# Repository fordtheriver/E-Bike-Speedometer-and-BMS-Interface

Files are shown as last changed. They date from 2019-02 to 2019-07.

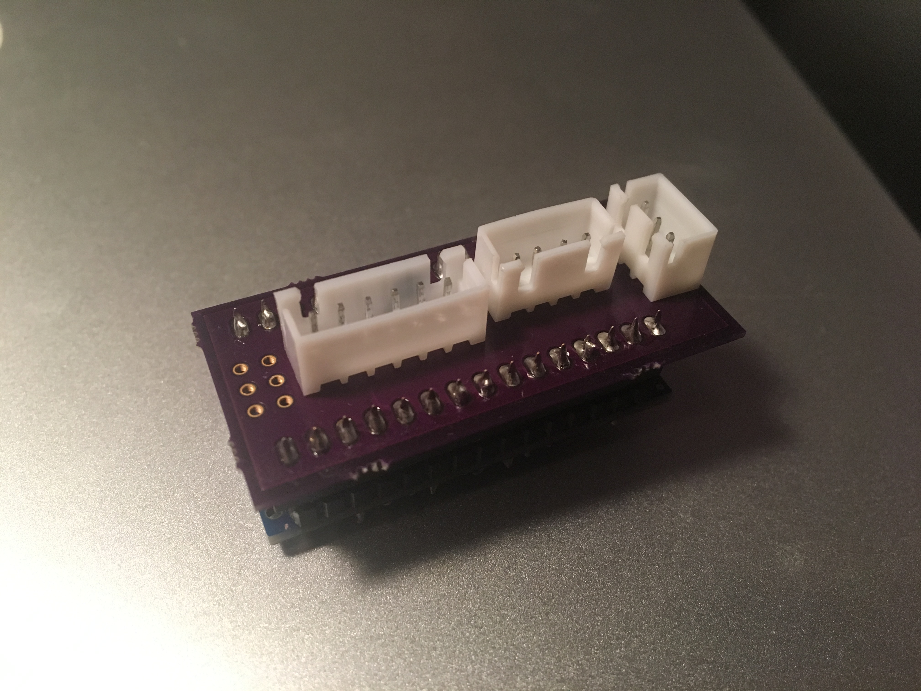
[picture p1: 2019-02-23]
Pictures/JST_Connectors.JPG

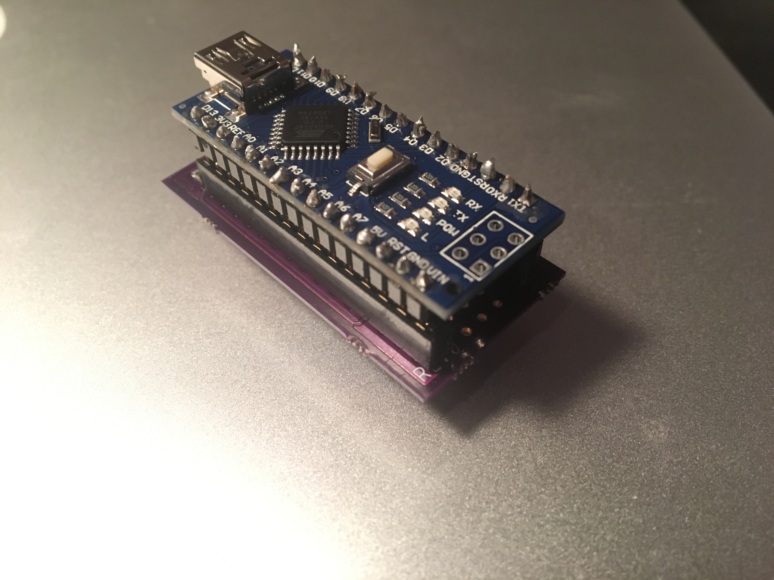
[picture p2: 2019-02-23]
Pictures/Arduino_Shield.JPG

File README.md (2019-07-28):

# E-Bike-Speedometer-and-BMS-Interface

**Updated 7/25/19** Completed, manufactured, and test REV4 of board. It works! REV3 is also complete.

This repository includes information needed to built a display to output the speed, mileage, power, current, pack voltage, individual cell voltage abd State of Charge of an electric bicycle/powerwall using an Arduino Nano! This repository includes the necessary Arduino files, a custom Arduino shield PCB designed in EAGLE and various information about the components required to build this system.

There are two versions of this system which you can build: <br /> 
**REV3:** This is a simple board that requires little soldering or PCB design experience. Beginners start here! <br /> 
**REV4:** This board is identical to REV3 but it embedds the arduino nano onto the board, instead of through-hole mounting a off-the-shelf arduino nano. <br /> 
Both REV's function identically. Think of REV3 as a demo board where you can develop firmware and prototype the system. REV4 gets into the low level side and allows for greater custimizations and smaller size.

Here is a brief list describing the necessary high level components for this system.

1. Arduino Nano. REV4 embeds the ATmega328P micrcoprocessor on the board to significantly reduce system size and weight. 

2. [20x4 LCD Display with I2C.](https://www.ebay.com/sch/i.html?_from=R40&_trksid=m570.l1313&_nkw=20x4+i2c+lcd+&_sacat=0). The I2C communication bus drastically reduces the number of wires going to the LCD and the \#include <LiquidCrystal_I2C.h> library seamlessly integrates the I2C protocol into your arduino. 

3. JBDTools Compatible BMS: Here is a [link](https://www.aliexpress.com/item/15S-Li-ion-Battery-Intelligent-Smart-BMS-with-Bluetooth-function-and-PC-software-UART-communication-PCB/32876909159.html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) to the one I purchased.  . Make sure the BMS you buy is compatible with JBDTools software. My arduino script uses the communication protocol used by the JBDTools software. This protocol can be found in an excel file call JBDTools Communication Protol at the homepage of this repository. [Simat](https://github.com/simat/BatteryMonitor/wiki/Generic-Chinese-Bluetooth-BMS-communication-protocol) also has a great description of it as well. 

4. DC/DC Converter. The linear voltage regulator on [this](https://www.aliexpress.com/item/15S-Li-ion-Battery-Intelligent-Smart-BMS-with-Bluetooth-function-and-PC-software-UART-communication-PCB/32876909159.html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) type of BMS is not designed to handle high amounts of current. REV3 of this project includes [this](https://www.mouser.com/ProductDetail/MEAN-WELL/SKM15C-12?qs=erfQA2AIGbWiXI5iTXq5SA%3D%3D) or [this](https://www.mouser.com/ProductDetail/Cincon/EC4SBW-48S12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) DC/DC converter to provide 12V at a max of 1.25A to the system.

5. [Hall effect sensor.](https://www.adafruit.com/product/158). This type of sensor send a HIGH pulse whenever a significant magnetic field acts upon it.

6. Connectors. [Housing](https://www.mouser.com/ProductDetail/Molex/70543-0001?qs=sGAEpiMZZMtVoztFdqDXOwZ%252B3K3gi96X). [Plug](https://www.mouser.com/ProductDetail/Molex/50-57-9402?qs=%2Fha2pyFaduiLH0020kLaRTyvVPMd9o3wI7LfZqK7vYk%3D). [Crimp Pin](https://www.mouser.com/ProductDetail/Molex/16-02-0086-Cut-Strip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)

7. EAGLE PCB design software. I used [OSHPark](https://oshpark.com/) to manufacture the PCB and had no issues. 

# High Level System Requirements:

1. Input Voltage Range: 18 - 72 Volts
2. Max Power Output at 12V: 1.67 Amps (20W)
3. Reverse polarity and fuse protection on power input

# Good Tips:

My ebike uses the Cyclone 3000 ebike kit. The throttle/ignition has a built in switch on the B+ line. My system draws power from the B+ after this switch so that if the switch opens, the system turns off. I recommend configuring your system this way so that it only draws power when the bike is on.

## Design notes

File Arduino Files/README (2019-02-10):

This Arduino sketch requires inclusion of the following libraries:

#include <Wire.h>
#include <LiquidCrystal_I2C.h>
#include <EEPROM.h>
#include <SoftwareSerial.h>

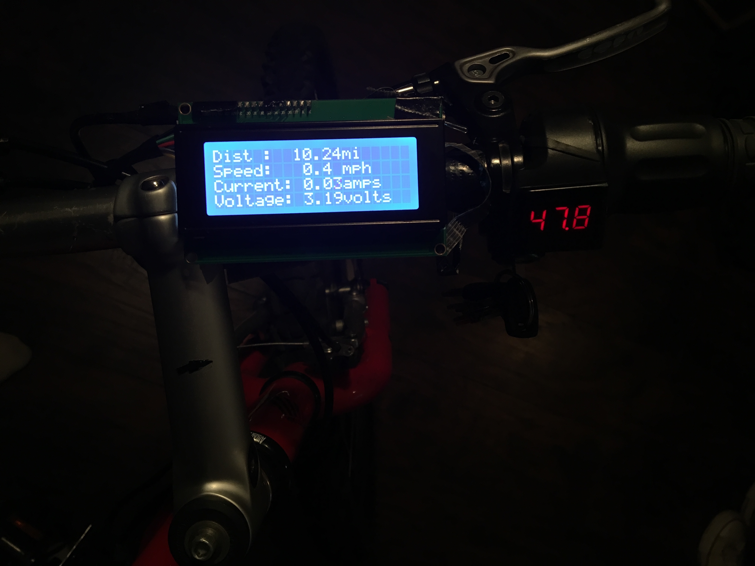
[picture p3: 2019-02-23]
Pictures/LCD_DIsplay.JPG

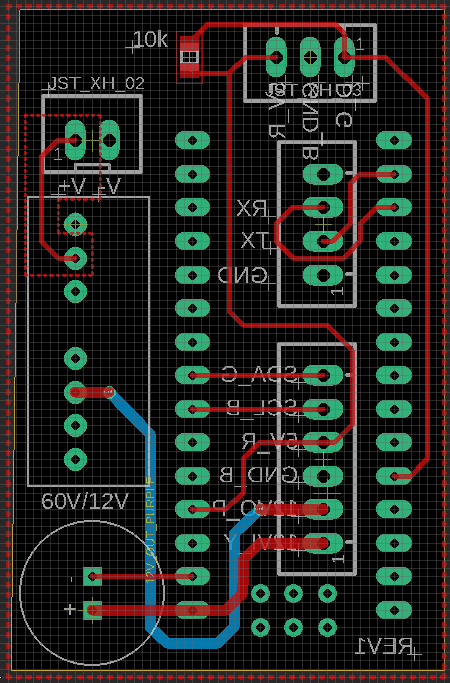
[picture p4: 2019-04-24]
Pictures/PCB_Desgin.png

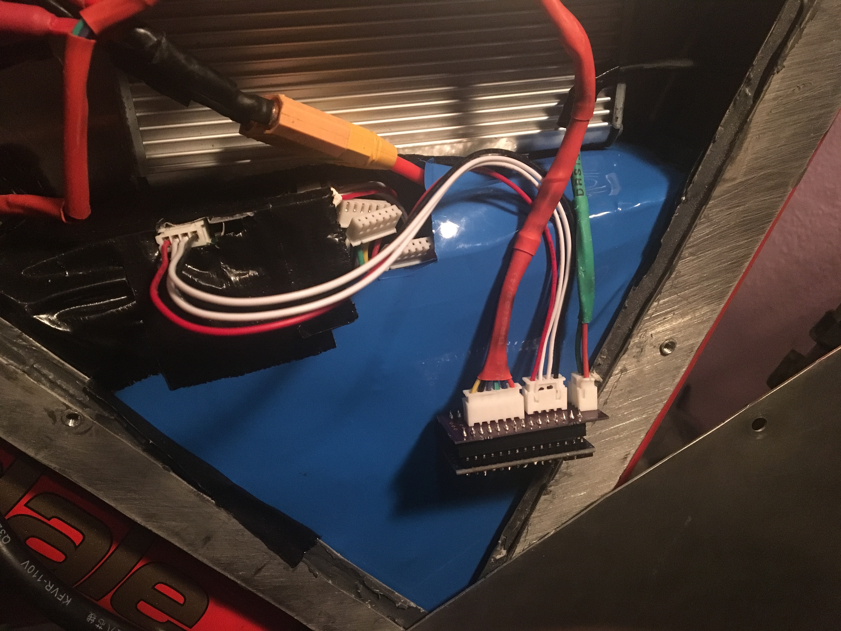
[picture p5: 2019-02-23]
Pictures/Embedded_System.JPG

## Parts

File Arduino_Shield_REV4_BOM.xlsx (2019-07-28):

Part | Value | Device | DESCRIPTION | LINK | PACKAGE | PART_NUMBER | PRICE | QTY
C1 | 100nF | CAPACITOR_100NF | Multilayer Ceramic Capacitors MLCC - SMD/SMT 0805 50V 0.1uF 10% X7R AEC-Q200 | https://www.mouser.com/ProductDetail/Taiyo-Yuden/UMK212B7104KGHT | 0805 | UMK212B7104KGHT | 0.073 | 2 | 0.146
C10 | 22pF | CAPACITOR_22PF | Multilayer Ceramic Capacitors MLCC - SMD/SMT 0805 22pF 50volts C0G 2% | https://www.mouser.com/ProductDetail/Vishay-Vitramon/VJ0805A220GXACW1BC | 0805 | VJ0805A220GXACW1BC | 0.19 | 2 | 0.38
C11 | 22pF | CAPACITOR_22PF | Multilayer Ceramic Capacitors MLCC - SMD/SMT 0805 22pF 50volts C0G 2% | https://www.mouser.com/ProductDetail/Vishay-Vitramon/VJ0805A220GXACW1BC | 0805 | VJ0805A220GXACW1BC | 0.19 | 2 | 0.38
C2 | 4.7uF_16V | CAPACITOR_POLAR_4.7UF | Tantalum Capacitors - Solid SMD 16volts 4.7uF 20% Molded Case, 0805 | https://www.mouser.com/ProductDetail/Vishay-Sprague/TMCP1C475MTRF | 0805 | TMCP1C475MTRF | 0.62 | 2 | 1.24
C3 | 1uF | CAPACITOR_1UF | Multilayer Ceramic Capacitors MLCC - SMD/SMT CGA 0805 16V 1uF X7R 10% AEC-Q200 | https://www.mouser.com/ProductDetail/TDK/CGA4J2X7R1C105K125AA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 | 0805 | CGA4J2X7R1C105K125AA | 0.08 | 2 | 0.16
C4 | 100nF | CAPACITOR_100NF | Multilayer Ceramic Capacitors MLCC - SMD/SMT 0805 50V 0.1uF 10% X7R AEC-Q200 | https://www.mouser.com/ProductDetail/Taiyo-Yuden/UMK212B7104KGHT | 0805 | UMK212B7104KGHT | 0.073 | 2 | 0.146
C5 | 4,7uF_16V | CAPACITOR_POLAR_4.7UF | Tantalum Capacitors - Solid SMD 16volts 4.7uF 20% Molded Case, 0805 | https://www.mouser.com/ProductDetail/Vishay-Sprague/TMCP1C475MTRF | 0805 | TMCP1C475MTRF | 0.62 | 2 | 1.24
C6 | 100nf | CAPACITOR_100NF | Multilayer Ceramic Capacitors MLCC - SMD/SMT 0805 50V 0.1uF 10% X7R AEC-Q200 | https://www.mouser.com/ProductDetail/Taiyo-Yuden/UMK212B7104KGHT | 0805 | UMK212B7104KGHT | 0.073 | 2 | 0.146
C7 | 1uF | CAPACITOR_1UF | Multilayer Ceramic Capacitors MLCC - SMD/SMT CGA 0805 16V 1uF X7R 10% AEC-Q200 | https://www.mouser.com/ProductDetail/TDK/CGA4J2X7R1C105K125AA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 | 0805 | CGA4J2X7R1C105K125AA | 0.08 | 2 | 0.16
C8 | 1uF | CAPACITOR_1UF | Multilayer Ceramic Capacitors MLCC - SMD/SMT CGA 0805 16V 1uF X7R 10% AEC-Q200 | https://www.mouser.com/ProductDetail/TDK/CGA4J2X7R1C105K125AA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 | 0805 | CGA4J2X7R1C105K125AA | 0.08 | 2 | 0.16
C9 | 100nF | CAPACITOR_100NF | Multilayer Ceramic Capacitors MLCC - SMD/SMT 0805 50V 0.1uF 10% X7R AEC-Q200 | https://www.mouser.com/ProductDetail/Taiyo-Yuden/UMK212B7104KGHT | 0805 | UMK212B7104KGHT | 0.073 | 2 | 0.146
CXTR_BMS | 4PIN_.1_CONNECTOR" | 4PIN_.1_CONNECTOR" | Headers & Wire Housings VERTICAL HDR 4P single row | https://www.mouser.com/ProductDetail/Molex/70543-0003 | 1X04 | 70543-0003 | 0.99 | 1 | 0.99
CXTR_DASH | 4PIN_.1_CONNECTOR" | 4PIN_.1_CONNECTOR" | Headers & Wire Housings VERTICAL HDR 4P single row | https://www.mouser.com/ProductDetail/Molex/70543-0003 | 1X04 | 70543-0003 | 0.99 | 2 | 1.98
CXTR_HALL_SENSOR | 3PIN_.1_CONNECTOR" | 3PIN_.1_CONNECTOR" | Headers & Wire Housings VERTICAL HDR 3P single row | https://www.mouser.com/ProductDetail/Molex/70543-0002?qs=sGAEpiMZZMtVoztFdqDXO7H2KtVwxa9m | 1X03 | 70543-0002 | 0.92 | 2 | 1.84
CXTR_HEADLIGHT | 2PIN_.1_CONNECTOR" | 2PIN_.1_CONNECTOR" | Headers & Wire Housings VERTICAL HDR 2P single row | https://www.mouser.com/ProductDetail/Molex/70543-0001?qs=sGAEpiMZZMtVoztFdqDXOwZ%252B3K3gi96X | 1X02 | 70543-0001 | 0.84 | 1 | 0.84
CXTR_POWER | 2PIN_.1_CONNECTOR" | 2PIN_.1_CONNECTOR" | Headers & Wire Housings VERTICAL HDR 2P single row | https://www.mouser.com/ProductDetail/Molex/70543-0001?qs=sGAEpiMZZMtVoztFdqDXOwZ%252B3K3gi96X | 1X02 | 70543-0001 | 0.84 | 2 | 1.68
D1 | SS1P3L | SCHOTTKY_DIODE | 1A 30V Schottky Barrier Rectifiers -SS1P3L-M3/84A | https://www.mouser.com/ProductDetail/Vishay-Semiconductors/SS1P3L-M3-84A | DO220AAL | SS1P3L-M3/84A | 0.44 | 2 | 0.88
D2 | ZENER | ZENER_DIODE | Zener Diodes PDZ10BGW/SOD123 SOD2 | https://www.mouser.com/ProductDetail/771-PDZ10BGWX | SOT123 | PDZ10BGWX | 0.16 | 3 | 0.48
DCDC_1 | EC4SBW-48S12 | DCDC_20W_EC4SBW-48S12 | Isolated DC/DC Converters DC-DC Converter, 20 Watt, 4:1 Input Range, 12VDC Output, 18-75VDC Input, 1670mA max., 1650uF | https://www.mouser.com/ProductDetail/418-EC4SBW48S12 |  | EC4SBW-48S12 | 34 | 1 | 34
F1 | MF-FSMF050X-2 | FUSE_RESETTABLE | Resettable Fuses - PPTC 6volts 40amps. Trip: 1 Amp | https://www.mouser.com/ProductDetail/Bourns/MF-FSMF050X-2 | 0603 | MF-FSMF050X-2 | 0.8 | 2 | 1.6
F2 | 0.5A_FUSE | FUSE12-6 | Surface Mount Fuses 1206 SMT Fuse VeryFastActing500mA | https://www.mouser.com/ProductDetail/Bel-Fuse/C1Q-500 | 1206 | C1Q 500 | 0.29 | 3 | 0.87
IC1 | FT232RL | USB<>UART_IC | USB to serial UART interface -FT232RL | https://www.mouser.com/ProductDetail/FTDI/FT232RL-REEL?qs=sGAEpiMZZMs5ceO8zL%252BTxyQLQIH6hE7q | SSOP28 | FT232RL | 4.5 | 1 | 4.5
IC2 | LM1117IMPX-5.0 | LINEAR_VREG | LDO Voltage Regulators 800MA | https://www.mouser.com/ProductDetail/Texas-Instruments/LM1117IMPX-50-NOPB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 | SOT-223-4 | LM1117IMPX-5.0/NOPB | 1.1 | 2 | 2.2
IC3 | 328P-MUR | ATMEGA328P_MURMUR | ATMEGA328P 8-bit Microcontroller with 32KBytes In-System Programmable Flash ATMEGA328P-AU | https://www.mouser.com/ProductDetail/Microchip-Technology-Atmel/ATMEGA328P-MUR?qs=6Dg1WZIWLC7u6Xm9ddn7Uw%3D%3D | chr | ATMEGA328P-MUR | 2.14 | 2 | 4.28
J3 | UJ2-MBH-1-SMT-TR | USB_MINI | USB Connectors USB 2.0 mini B jack 5 pin Horizontal SMT | https://www.mouser.com/ProductDetail/CUI/UJ2-MBH-1-SMT-TR | USB-MINI-B_2 | UJ2-MBH-1-SMT-TR | 0.49 | 2 | 0.98
J4 |  | 2X3_.1_ARRAY" | 2X03 Array of 0.1 Headers" | n/a | n/a |  | 0 | 0 | 0
L | Green | LED_GREEN | LED GREEN - SMD-0805 | https://www.mouser.com/ProductDetail/Kingbright/APT2012CGCK | 0805 | APT2012CGCK | 0.176 | 3 | 0.528
PWR | Green | LED_GREEN | LED GREEN - SMD-0805 | https://www.mouser.com/ProductDetail/Kingbright/APT2012CGCK | 0805 | APT2012CGCK | 0.176 | 3 | 0.528
R1 | 4.99 | RESISTOR_4.99K_0805-0805-1/8W-1% | Thick Film Resistors 1/8Watt 4.99Kohms 1% Commercial Use | https://www.mouser.com/ProductDetail/Vishay-Dale/CRCW08054K99FKEAC | 0805 | CRCW08054K99FKEAC | 0.1 | 2 | 0.2
R2 | 10K | RESISTOR_100K_0805-0805-1/8W-1% | Thick Film Resistors - SMD 0805 100Kohms 1% AEC-Q200 | https://www.mouser.com/ProductDetail/667-ERJ-6ENF1003V | 805 | ERJ-6ENF1003V | 0.1 | 3 | 0.3
RESONATOR | CSTNE16M0VH3C000R0 | RESONATOR | Resonators 16.0000MHz 15pF SMD CHP Rsntr 0.07% AUTO | https://www.mouser.com/ProductDetail/Murata-Electronics/CSTNE16M0VH3C000R0 | CUSTOM | CSTNE16M0VH3C000R0 | 0.44 | 3 | 1.32
RP1 | 1K | RESISTOR_ARRAY | Resistor Networks & Arrays 1K 5% Convex 4resistors | https://www.mouser.com/ProductDetail/Bourns/CAY16-102J4LF | CAY16 | CAY16-102J4LF | 0.1 | 2 | 0.2
RP2 | 1K | RESISTOR_ARRAY | Resistor Networks & Arrays 1K 5% Convex 4resistors | https://www.mouser.com/ProductDetail/Bourns/CAY16-102J4LF | CAY16 | CAY16-102J4LF | 0.1 | 2 | 0.2
RX | Green | LED_GREEN | LED GREEN - SMD-0805 | https://www.mouser.com/ProductDetail/Kingbright/APT2012CGCK | 0805 | APT2012CGCK | 0.176 | 2 | 0.352
T1 | PMOS_BSP322PH6327XTSA1 | PMOS | MOSFET P-Ch -100V 1A SOT-223-3 | https://www.mouser.com/ProductDetail/726-BSP322PH6327XTSA | SOT-223 | BSP322PH6327XTSA1 | 0.72 | 2 | 1.44
TX | Green | LED_GREEN | LED GREEN - SMD-0805 | https://www.mouser.com/ProductDetail/Kingbright/APT2012CGCK | 0805 | APT2012CGCK | 0.176 | 2 | 0.352
 |  | 2PIN_.1_PLUG | Headers & Wire Housings HSG 2P SINGLE ROW POSITIVE LATCH | https://www.mouser.com/ProductDetail/Molex/50-57-9402 | 1X02 | 50-57-9402 | 0.27 | 3 | 0.81
 |  | 3PIN_.1_PLUG | Headers & Wire Housings HSG 3P SINGLE ROW POSITIVE LATCH | https://www.mouser.com/ProductDetail/Molex/50-57-9403 | 1X03 | 50-57-9403 | 0.23 | 2 | 0.46
 |  | 4PIN_.1_PLUG | Headers & Wire Housings HSG 4P SINGLE ROW POSITIVE LATCH | https://www.mouser.com/ProductDetail/Molex/50-57-9404 | 1x04 | 50-57-9404 | 0.26 | 3 | 0.78
 |  | Crimp Pins |  | https://www.mouser.com/ProductDetail/Molex/16-02-0086-Cut-Strip | n/a | 16-02-0086 (Cut Strip) | 0.052 | 100 | 5.2
 |  |  |  |  |  |  |  |  | 74.094

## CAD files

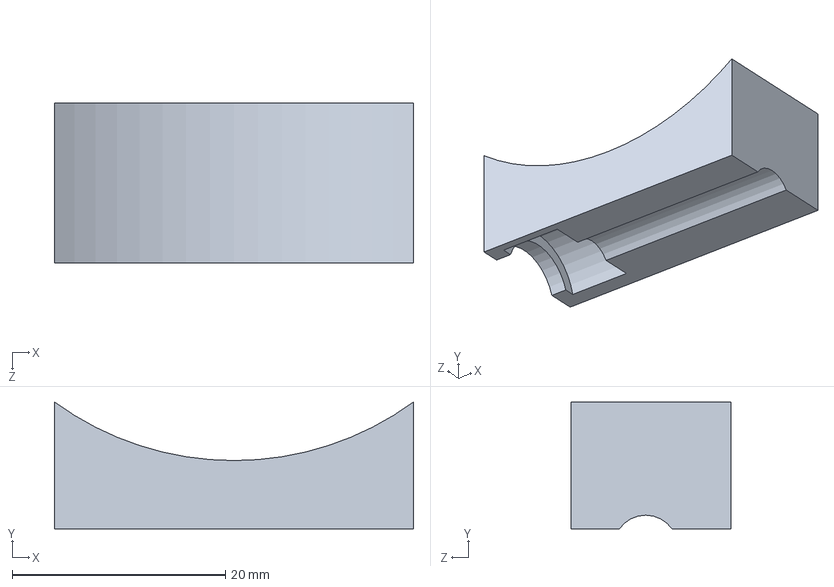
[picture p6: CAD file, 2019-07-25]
Cyclone_3000_Motor Spacer/Spacer_REV3_07_09_19.SLDPRT
33.7 x 11.9 x 15.0 mm

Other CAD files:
Cyclone_3000_Motor Spacer/Spacer_REV3_07_09_19.STL

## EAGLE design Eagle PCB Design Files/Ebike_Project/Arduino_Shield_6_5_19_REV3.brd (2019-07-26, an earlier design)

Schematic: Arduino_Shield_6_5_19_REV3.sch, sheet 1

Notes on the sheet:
Connector Housing Series 70543 - Part No: 705430004 (4 PIN)
Connector Plug Series 70066 - Part No: 505794XX
Connector Crimp Series 70058 - Part No: 16020086
Wire to Wire Housing Crimp: 70021-1021
Wire to Wire Housing Series: 70107 - Part No: 701070003
BMS_SWITCH
IGNITION_SWITCH

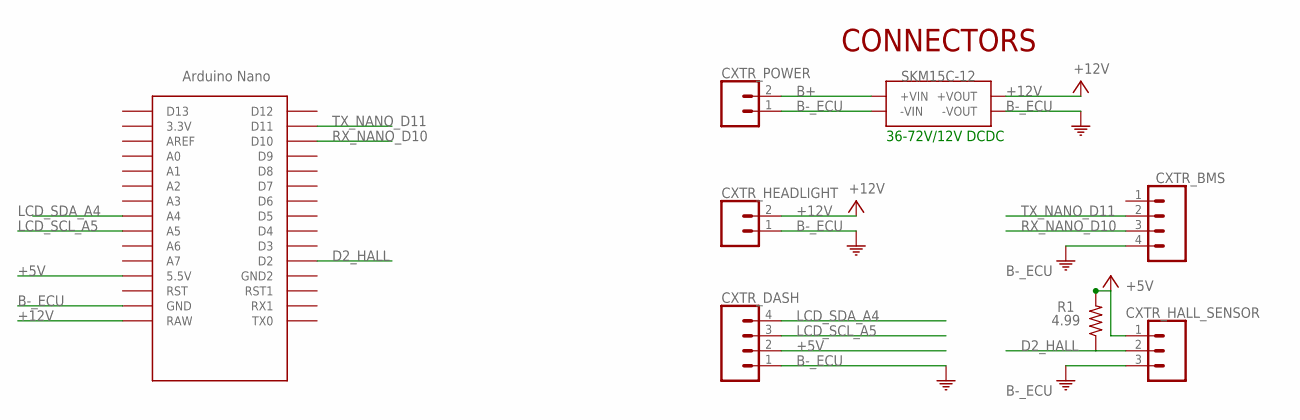
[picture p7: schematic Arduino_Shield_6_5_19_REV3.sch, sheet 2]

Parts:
CXTR_BMS: 4PIN_.1"_CONNECTOR; 1X04
CXTR_DASH: 4PIN_.1"_CONNECTOR; 1X04
CXTR_HALL_SENSOR: 3PIN_.1"_CONNECTOR; 1X03
CXTR_HEADLIGHT: 2PIN_.1"_CONNECTOR; 1X02
CXTR_POWER: 2PIN_.1"_CONNECTOR; 1X02
R1: 4.99; 0805
U$2: SKM15C-12_DCDC
U$3: ARDUINO_NANO; NANO

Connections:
+5V: CXTR_DASH.2, CXTR_HALL_SENSOR.1, R1.2, U$3.5V (5.5V)
+12V: CXTR_HEADLIGHT.2, U$2.+VOUT, U$3.RAW
B+: CXTR_POWER.2, U$2.+VIN
B-_ECU: CXTR_BMS.4, CXTR_DASH.1, CXTR_HALL_SENSOR.3, CXTR_HEADLIGHT.1, CXTR_POWER.1, U$2.-VIN, U$2.-VOUT, U$3.GND
D2_HALL: CXTR_HALL_SENSOR.2, R1.1, U$3.D2
LCD_SCL_A5: CXTR_DASH.3, U$3.A5
LCD_SDA_A4: CXTR_DASH.4, U$3.A4
RX_NANO_D10: CXTR_BMS.3, U$3.D10
TX_NANO_D11: CXTR_BMS.2, U$3.D11

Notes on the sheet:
36-72V/12V DCDC
CONNECTORS

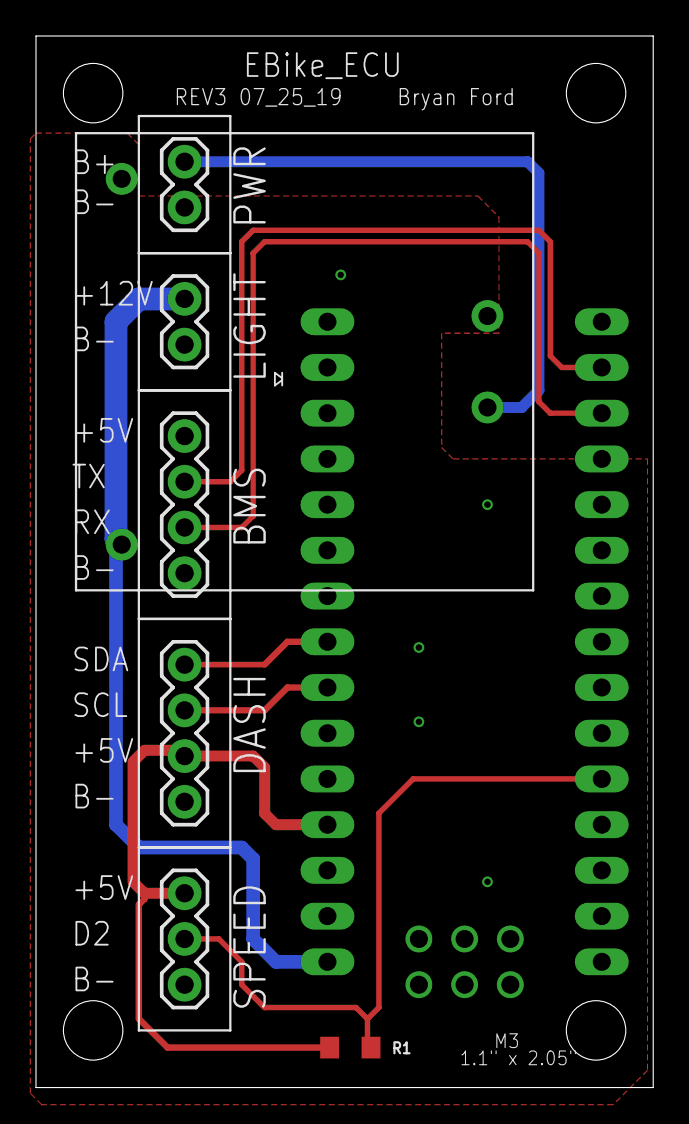
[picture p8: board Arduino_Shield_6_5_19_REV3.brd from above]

Board: 2 copper layers, 34.3 x 58.4 mm, 8 parts (0 on the bottom side), 9 nets.

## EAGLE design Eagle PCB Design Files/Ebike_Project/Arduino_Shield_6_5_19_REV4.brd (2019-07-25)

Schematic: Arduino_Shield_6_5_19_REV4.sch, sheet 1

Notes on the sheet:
Connector Housing Series 70543 - Part No: 705430004 (4 PIN)
Connector Plug Series 70066 - Part No: 505794XX
Connector Crimp Series 70058 - Part No: 16020086
Wire to Wire Housing Crimp: 70021-1021
Wire to Wire Housing Series: 70107 - Part No: 701070003
BMS_SWITCH
IGNITION_SWITCH

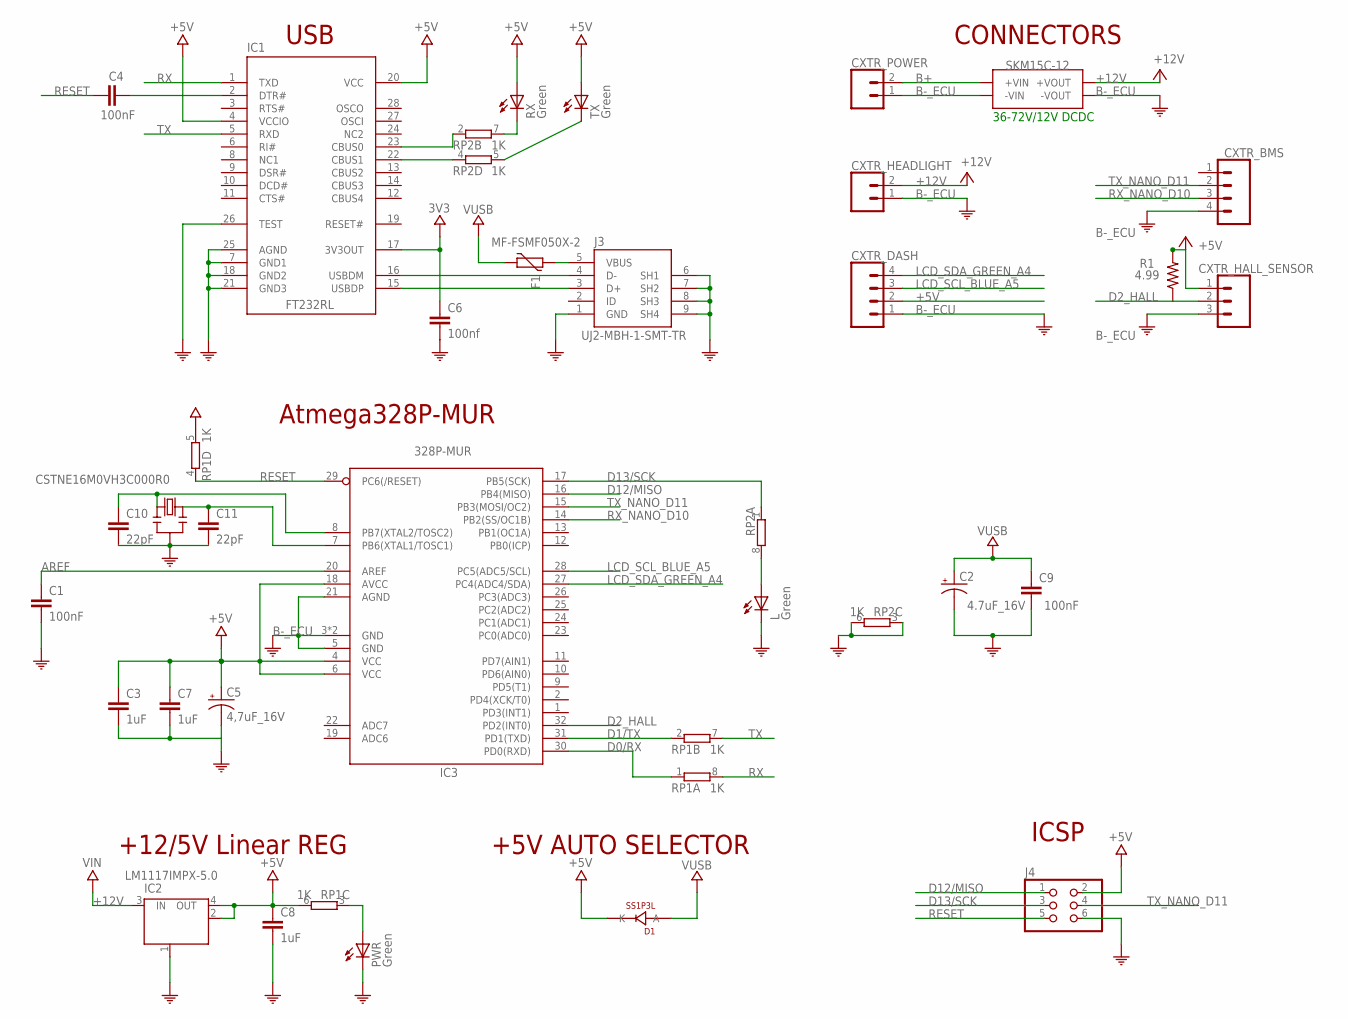
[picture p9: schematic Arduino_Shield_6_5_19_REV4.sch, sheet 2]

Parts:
C1, C4, C9: 100nF; 0805
C2: 4.7uF_16V; 0805
C3, C7, C8: 1uF; 0805
C5: 4,7uF_16V; 0805
C6: 100nf; 0805
C10, C11: 22pF; 0805
CXTR_BMS: 4PIN_.1"_CONNECTOR; 1X04
CXTR_DASH: 4PIN_.1"_CONNECTOR; 1X04
CXTR_HALL_SENSOR: 3PIN_.1"_CONNECTOR; 1X03
CXTR_HEADLIGHT: 2PIN_.1"_CONNECTOR; 1X02
CXTR_POWER: 2PIN_.1"_CONNECTOR; 1X02
D1: SS1P3L; SCHOTTKY_DIODE_DO220AAL
F1: MF-FSMF050X-2; 0603
IC1: FT232RL; USB_SSOP28
IC2: LM1117IMPX-5.0; LINEAR_VREG_SOT223
IC3: 328P-MUR; VQFN32
J3: UJ2-MBH-1-SMT-TR; USB-MINI-B_2
J4: 2X3_.1"_ARRAY; 2X03
L: Green; LED_0805
PWR: Green; LED_0805
R1: 4.99; 0805
RESONATOR: CSTNE16M0VH3C000R0; CRISTALLI_RESONATOR
RP1, RP2: 1K; RESISTOR_ARRAY_CAY16
RX: Green; LED_0805
TX: Green; LED_0805
U$2: SKM15C-12_DCDC

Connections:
3V3: C6.1, IC1.17 (3V3OUT)
+5V: C3.1, C5.1 (+), C7.1, C8.1, CXTR_DASH.2, CXTR_HALL_SENSOR.1, D1.P$1 (K), IC1.4 (VCCIO), IC1.20 (VCC), IC2.2 (OUT), IC2.4 (OUT), IC3.4 (VCC), IC3.6 (VCC), IC3.18 (AVCC), J4.2, R1.2, RP1.5 (2), RP1.6 (2), RX.A, TX.A
+12V: CXTR_HEADLIGHT.2, IC2.3 (IN), U$2.+VOUT
AREF: C1.1, IC3.20 (AREF)
B+: CXTR_POWER.2, U$2.+VIN
B-_ECU: C1.2, C2.2 (-), C3.2, C5.2 (-), C6.2, C7.2, C8.2, C9.2, C10.2, C11.2, CXTR_BMS.4, CXTR_DASH.1, CXTR_HALL_SENSOR.3, CXTR_HEADLIGHT.1, CXTR_POWER.1, IC1.7 (GND1), IC1.18 (GND2), IC1.21 (GND3), IC1.25 (AGND), IC1.26 (TEST), IC2.1 (GND/ADJ), IC3.3 (GND), IC3.5 (GND), IC3.21 (AGND), IC3.33 (GND), J3.1 (GND), J3.6 (SH1), J3.7 (SH2), J3.8 (SH3), J3.9 (SH4), J4.6, L.C, PWR.C, RESONATOR.2, RP2.3 (1), RP2.6 (2), U$2.-VIN, U$2.-VOUT
D0/RX: IC3.30 (PD0(RXD)), RP1.1
D1/TX: IC3.31 (PD1(TXD)), RP1.2 (1)
D2_HALL: CXTR_HALL_SENSOR.2, IC3.32 (PD2(INT0)), R1.1
D12/MISO: IC3.16 (PB4(MISO)), J4.1
D13/SCK: IC3.17 (PB5(SCK)), J4.3, RP2.1
LCD_SCL_BLUE_A5: CXTR_DASH.3, IC3.28 (PC5(ADC5/SCL))
LCD_SDA_GREEN_A4: CXTR_DASH.4, IC3.27 (PC4(ADC4/SDA))
unnamed: C4.2, IC1.2 (DTR#)
unnamed: IC1.15 (USBDP), J3.3 (D+)
unnamed: IC1.16 (USBDM), J3.4 (D-)
unnamed: PWR.A, RP1.3 (1)
unnamed: IC1.23 (CBUS0), RP2.2 (1)
unnamed: IC1.22 (CBUS1), RP2.4 (1)
unnamed: C11.1, IC3.7 (PB6(XTAL1/TOSC1)), RESONATOR.1
unnamed: L.A, RP2.8 (2)
unnamed: RP2.5 (2), TX.C
unnamed: C10.1, IC3.8 (PB7(XTAL2/TOSC2)), RESONATOR.3
unnamed: F1.2, J3.5 (VBUS)
unnamed: RP2.7 (2), RX.C
RESET: C4.1, IC3.29 (PC6(/RESET)), J4.5, RP1.4 (1)
RX: IC1.1 (TXD), RP1.8 (2)
RX_NANO_D10: CXTR_BMS.3, IC3.14 (PB2(SS/OC1B))
TX: IC1.5 (RXD), RP1.7 (2)
TX_NANO_D11: CXTR_BMS.2, IC3.15 (PB3(MOSI/OC2)), J4.4
VUSB: C2.1 (+), C9.1, D1.P$2 (A), F1.1

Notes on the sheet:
+12/5V Linear REG
ICSP
USB
+5V AUTO SELECTOR
36-72V/12V DCDC
Atmega328P-MUR
CONNECTORS

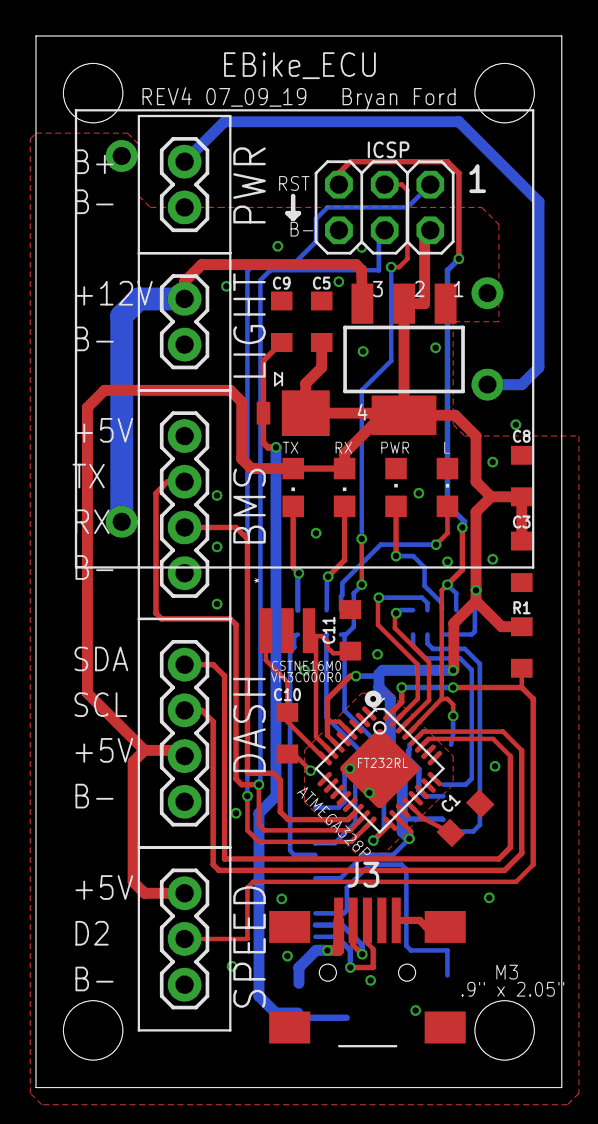
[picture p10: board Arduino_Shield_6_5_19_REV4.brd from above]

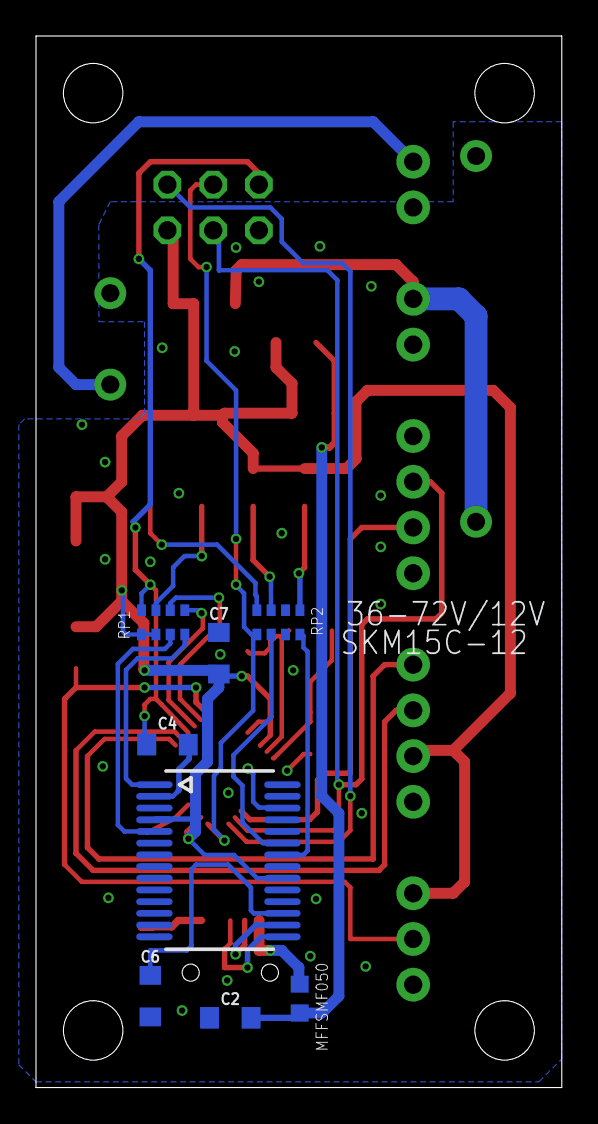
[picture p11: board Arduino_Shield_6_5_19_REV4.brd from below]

Board: 2 copper layers, 29.2 x 58.4 mm, 32 parts (8 on the bottom side), 31 nets.

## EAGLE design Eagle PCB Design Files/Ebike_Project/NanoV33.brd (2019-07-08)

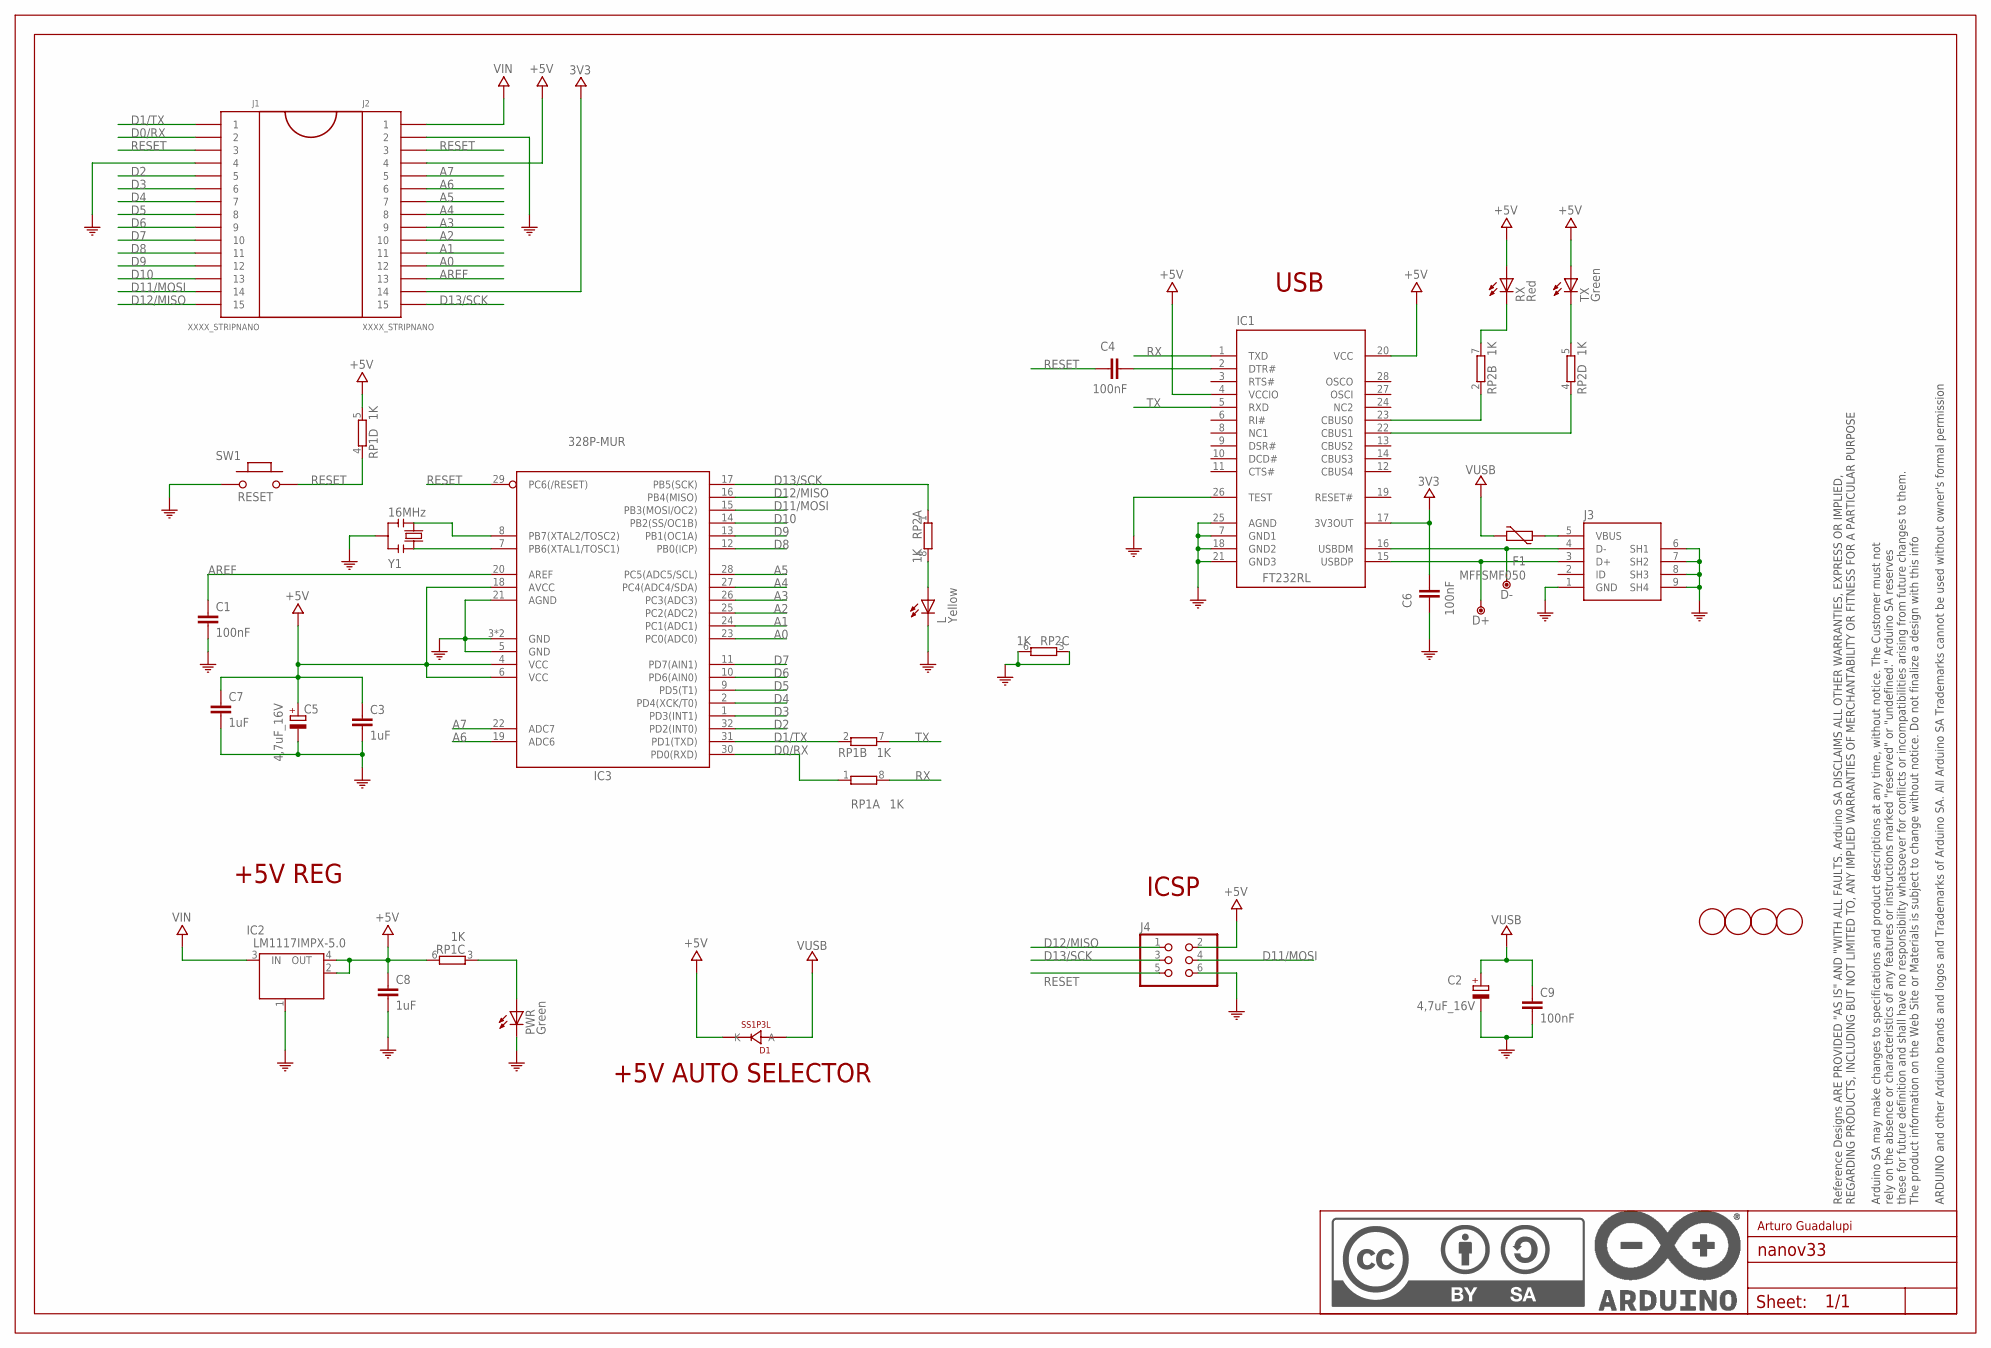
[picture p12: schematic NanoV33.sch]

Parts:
C1, C4, C6, C9: 100nF; C0603-ROUND
C2, C5: 4,7uF_16V; TAN-A
C3, C7, C8: 1uF; C0603-ROUND
D1: SS1P3L; DO220AAL
D+: DNP; TP-1.00MM
D-: DNP; TP-1.00MM
F1: MFFSMF050; 0603-1608X90N
FRAME1: DNP; FRAME
IC1: FT232RL; SSOP28
IC2: LM1117IMPX-5.0; LINEAR_SOT223
IC3: 328P-MUR; VQFN32
J1, J2: XXXX_STRIPNANO; HEAD15-NOSS
J3: 0219_14850; USB-MINI-B_2
J4: 0114_PH254-203DF118A00V; 2X03
L: Yellow; CHIPLED_0805
PWR: Green; CHIPLED_0805
RP1, RP2: 1K; CAY16
RX: Red; CHIPLED_0805
SW1: RESET; SMD_157SW
TX: Green; CHIPLED_0805
U$4, U$5, U$53, U$54: DNP; FD-1-1.5
Y1: 16MHz; RESONATOR

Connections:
3V3: C6.2, IC1.17 (3V3OUT), J2.14
+5V: C3.1, C5.1 (+), C7.1, C8.1, D1.P$1 (K), IC1.4 (VCCIO), IC1.20 (VCC), IC2.2 (OUT), IC2.4 (OUT), IC3.4 (VCC), IC3.6 (VCC), IC3.18 (AVCC), J2.4, J4.2, RP1.5 (2), RP1.6 (2), RX.A, TX.A
A0: IC3.23 (PC0(ADC0)), J2.12
A1: IC3.24 (PC1(ADC1)), J2.11
A2: IC3.25 (PC2(ADC2)), J2.10
A3: IC3.26 (PC3(ADC3)), J2.9
A4: IC3.27 (PC4(ADC4/SDA)), J2.8
A5: IC3.28 (PC5(ADC5/SCL)), J2.7
A6: IC3.19 (ADC6), J2.6
A7: IC3.22 (ADC7), J2.5
AREF: C1.1, IC3.20 (AREF), J2.13
COM: C1.2, C2.2 (-), C3.2, C5.2 (-), C6.1, C7.2, C8.2, C9.2, IC1.7 (GND1), IC1.18 (GND2), IC1.21 (GND3), IC1.25 (AGND), IC1.26 (TEST), IC2.1 (GND/ADJ), IC3.3 (GND), IC3.5 (GND), IC3.21 (AGND), IC3.33 (GND), J1.4, J2.2, J3.1 (GND), J3.6 (SH1), J3.7 (SH2), J3.8 (SH3), J3.9 (SH4), J4.6, L.C, PWR.C, RP2.3 (1), RP2.6 (2), SW1.1, Y1.2
D0/RX: IC3.30 (PD0(RXD)), J1.2, RP1.1
D1/TX: IC3.31 (PD1(TXD)), J1.1, RP1.2 (1)
D2: IC3.32 (PD2(INT0)), J1.5
D3: IC3.1 (PD3(INT1)), J1.6
D4: IC3.2 (PD4(XCK/T0)), J1.7
D5: IC3.9 (PD5(T1)), J1.8
D6: IC3.10 (PD6(AIN0)), J1.9
D7: IC3.11 (PD7(AIN1)), J1.10
D8: IC3.12 (PB0(ICP)), J1.11
D9: IC3.13 (PB1(OC1A)), J1.12
D10: IC3.14 (PB2(SS/OC1B)), J1.13
D11/MOSI: IC3.15 (PB3(MOSI/OC2)), J1.14, J4.4
D12/MISO: IC3.16 (PB4(MISO)), J1.15, J4.1
D13/SCK: IC3.17 (PB5(SCK)), J2.15, J4.3, RP2.1
unnamed: IC3.8 (PB7(XTAL2/TOSC2)), Y1.3
unnamed: IC3.7 (PB6(XTAL1/TOSC1)), Y1.1
unnamed: PWR.A, RP1.3 (1)
unnamed: C4.2, IC1.2 (DTR#)
unnamed: D+.X, IC1.15 (USBDP), J3.3 (D+)
unnamed: D-.X, IC1.16 (USBDM), J3.4 (D-)
unnamed: L.A, RP2.8 (2)
unnamed: IC1.23 (CBUS0), RP2.2 (1)
unnamed: IC1.22 (CBUS1), RP2.4 (1)
unnamed: RP2.5 (2), TX.C
unnamed: F1.2, J3.5 (VBUS)
unnamed: RP2.7 (2), RX.C
RESET: C4.1, IC3.29 (PC6(/RESET)), J1.3, J2.3, J4.5, RP1.4 (1), SW1.2
RX: IC1.1 (TXD), RP1.8 (2)
TX: IC1.5 (RXD), RP1.7 (2)
VIN: IC2.3 (IN), J2.1
VUSB: C2.1 (+), C9.1, D1.P$2 (A), F1.1

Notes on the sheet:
+5V REG
ICSP
USB
+5V AUTO SELECTOR
Arturo Guadalupi



Board: 2 copper layers, 43.2 x 17.8 mm, 33 parts (17 on the bottom side), 43 nets.

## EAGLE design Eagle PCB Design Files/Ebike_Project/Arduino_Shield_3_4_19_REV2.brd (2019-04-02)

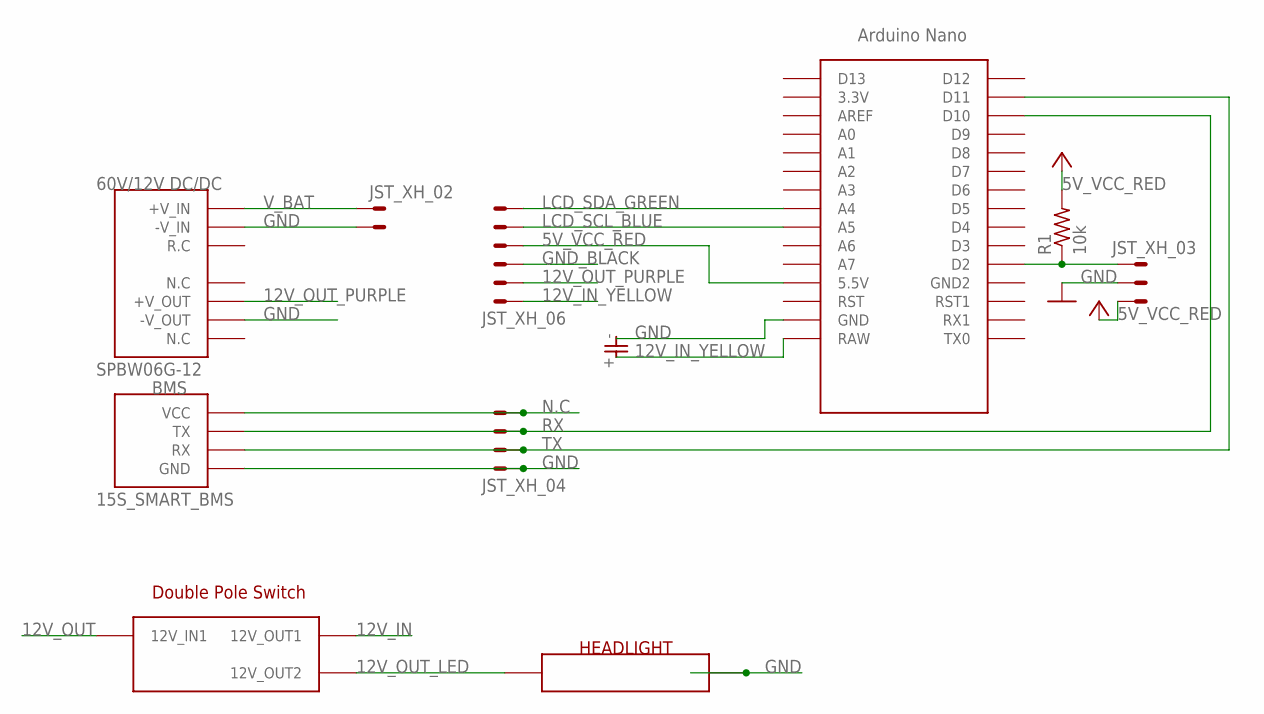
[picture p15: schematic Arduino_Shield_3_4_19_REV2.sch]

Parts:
R1: 10k; R0805
U$1: NANO
U$2: SPBW06G-12
U$3: THROUGHHOLE_CAP
X1: JST_XH_04; JST-XH-04-PACKAGE-LONG-PAD
X2: JST_XH_06; JST-XH-06-PACKAGE-LONG-PAD
X4: JST_XH_02; JST-XH-02-PACKAGE-LONG-PAD
X5: JST_XH_03; JST-XH-03-PACKAGE-LONG-PAD

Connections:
5V_VCC_RED: R1.2, U$1.5V (5.5V), X2.4, X5.3
12V_IN_YELLOW: U$1.RAW, U$3.+, X2.1
12V_OUT_PURPLE: U$2.+V_OUT, X2.2
GND: U$1.GND, U$2.-V_IN, U$2.-V_OUT, U$3.-, X1.1, X4.2, X5.2
GND_BLACK: X2.3
LCD_SCL_BLUE: U$1.A5, X2.5
LCD_SDA_GREEN: U$1.A4, X2.6
unnamed: R1.1, U$1.D2, X5.1
N.C: X1.4
RX: U$1.D10, X1.3
TX: U$1.D11, X1.2
V_BAT: U$2.+V_IN, X4.1

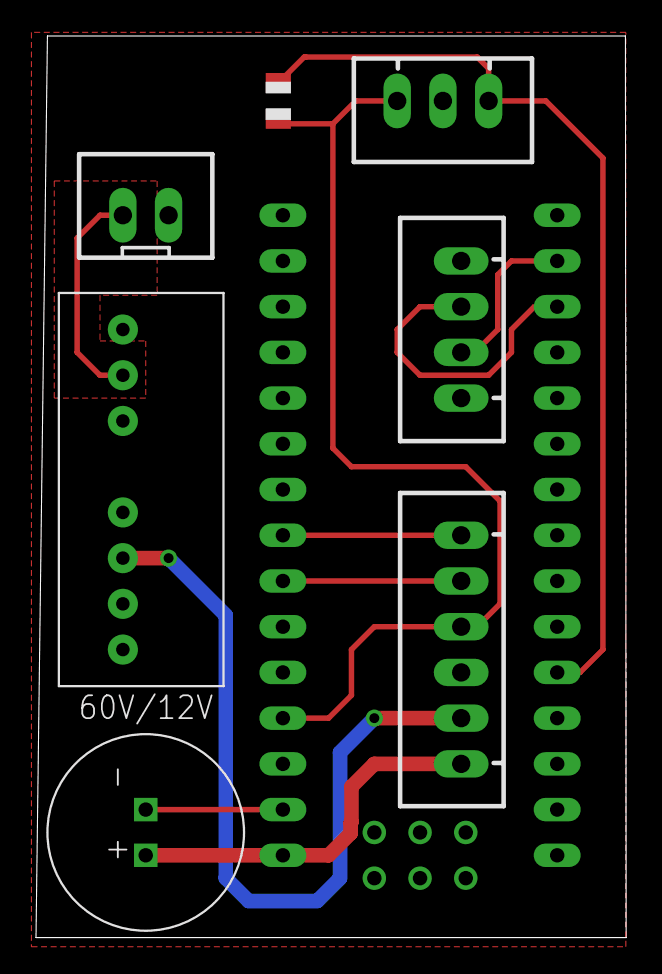
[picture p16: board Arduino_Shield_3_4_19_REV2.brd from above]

Board: 2 copper layers, 32.8 x 50.1 mm, 8 parts (0 on the bottom side), 10 nets.

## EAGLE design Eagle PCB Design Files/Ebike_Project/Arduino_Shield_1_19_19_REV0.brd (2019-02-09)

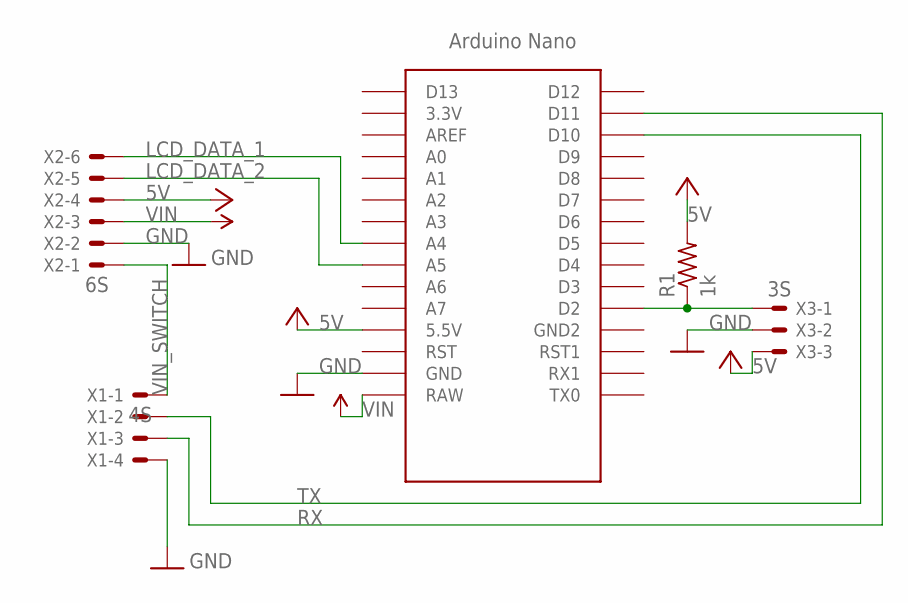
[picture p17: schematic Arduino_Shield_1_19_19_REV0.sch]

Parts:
R1: 1k; R0805
U$1: NANO
X1: 4S; JST-XH-04-PACKAGE-ROUND-PAD
X2: 6S; JST-XH-06-PACKAGE-ROUND-PAD
X3: 3S; JST-XH-03-PACKAGE-ROUND-PAD

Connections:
5V: R1.2, U$1.5V (5.5V), X2.4, X3.3
GND: U$1.GND, X1.4, X2.2, X3.2
LCD_DATA_1: U$1.A4, X2.6
LCD_DATA_2: U$1.A5, X2.5
unnamed: R1.1, U$1.D2, X3.1
RX: U$1.D11, X1.3
TX: U$1.D10, X1.2
VIN: U$1.RAW, X2.3
VIN_SWITCH: X1.1, X2.1

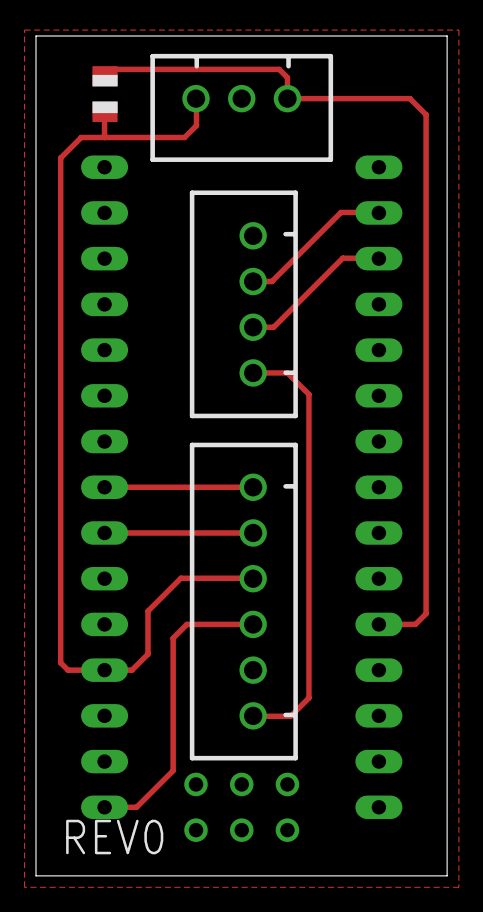
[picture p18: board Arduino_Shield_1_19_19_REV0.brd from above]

Board: 2 copper layers, 22.8 x 46.7 mm, 5 parts (0 on the bottom side), 9 nets.

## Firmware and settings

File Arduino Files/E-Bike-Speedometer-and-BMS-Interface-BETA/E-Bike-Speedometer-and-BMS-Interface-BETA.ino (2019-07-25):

//SPEEDOMETER FOR EBIKE
//Created by: Bryan Ford 10/21/18

double bikeVel;
double pi = 3.14159265;
double w = 0;
double Distance = 0.0;
double Distance_mem = 186.46;
int savedDistance = 0;
int wheelDiam_in = 26;
int timeDelay = 2000;
unsigned long rotCount_old = 0;
unsigned long oldTime = 2000;
volatile unsigned long rotCount = 0;
volatile unsigned long lastTime;
volatile double interval = 10000000;
volatile int HallIn = 2;

//BMS Variables
byte byte_Amps[2];
byte Cell_Volt[30];
byte byte_Array[34];
unsigned long time1;
double Current_A;
double Voltages_V[15];

//I2C LIBRARY ADDITION
// Include Wire Library for I2C
#include <Wire.h>
// Include NewLiquidCrystal Library for I2C
#include <LiquidCrystal_I2C.h>
// Define LCD pinout
const int  en = 2, rw = 1, rs = 0, d4 = 4, d5 = 5, d6 = 6, d7 = 7, bl = 3;
// Define I2C Address - change if reqiuired
const int i2c_addr = 0x27;
LiquidCrystal_I2C lcd(i2c_addr, en, rw, rs, d4, d5, d6, d7, bl, POSITIVE);

//EEPROM LIBRARY ADDITION
#include <EEPROM.h>
int addr = 0;

#include <SoftwareSerial.h> // This allows two digital pins to act as RX and TX to an external serial device
SoftwareSerial portOne(10, 11); // software serial #1: RX = digital pin 10, TX = digital pin 11

//Executed when Arduino receives a "RISING" digital input from Hall Sensor
void pin_ISR() {
  interval = millis() - lastTime;
  lastTime = millis();
  rotCount++;
}


void setup() {
  Serial.begin(9600);
  // Attach an interrupt to the ISR vector
  attachInterrupt(digitalPinToInterrupt(HallIn), pin_ISR, RISING); //HallIn = 2. Pin 2 is an interupt pin
  // Start each software serial port
  portOne.begin(9600);
  // set up the LCD's number of columns and rows:
  setDisplay(); // See setDisplay function

  //Retrive mileage data

  if(EEPROM.read(addr) == 255){
    Distance = Distance_mem;
  }else{
    EEPROM.get(addr, Distance);
  }
}

struct Packet1 {
  byte garbage1[6];
  int16_t current;
  byte garbage2[26];
};
union Converter1 {
  Packet1 p;
  byte d[34];
} converter1;
struct Packet2 {
  byte garbage1[4];
  int16_t Volt1[2]; int16_t Volt2[2];  int16_t Volt3[2]; int16_t Volt4[2]; int16_t Volt5[2];
  int16_t Volt6[2]; int16_t Volt7[2];  int16_t Volt8[2]; int16_t Volt9[2]; int16_t Volt10[2];
  int16_t Volt11[2]; int16_t Volt12[2]; int16_t Volt13[2]; int16_t Volt14[2]; int16_t Volt15[2];
  byte garbage2[3];
};
union Converter2 {
  Packet2 p;
  byte d[37];
} converter2;
union ByteSwap {
  byte b_array[2];
  int16_t swapped;
} ByteSwap;


void loop() {

  //if two seconds have passed since last save & the wheel has rotated, calculate new milage and save
  if (millis() - oldTime > timeDelay && rotCount_old != rotCount) {
    Distance = Distance + pi * wheelDiam_in / 12 / 5280 * (rotCount - rotCount_old);
    Serial.print("Distance ");
    Serial.println(Distance);
    EEPROM.put(addr, Distance); //saves mileage to specificed address in EEPROM
    rotCount_old = rotCount;
    oldTime = millis();
  }

  //Distance Display Formatting
  if (Distance > 999.99) {
    lcd.setCursor(8, 0); lcd.print(Distance, 2);
  }
  else if (Distance > 99.99) {
    lcd.setCursor(9, 0); lcd.print(Distance, 2);
  }
  else if (Distance > 9.99) {
    lcd.setCursor(10, 0); lcd.print(Distance, 2);
  }
  else {
    lcd.setCursor(11, 0); lcd.print(Distance, 2);
  }

  //Velocity Calculation and Display
  w = 1 / (interval / 1000);
  bikeVel = w * pi * 3600 * wheelDiam_in / 12 / 5280;
  if (bikeVel > 9.999)
  {
    lcd.setCursor(10, 1);
  }
  else {
    lcd.setCursor(10, 1);
    lcd.print(" ");
  }
  lcd.print(bikeVel, 1);

  byte message[] = {0xdd, 0xa5, 0x03, 0x00, 0xff, 0xfd, 0x77}; //This is a byte array that is an info request to the BMS
  time1 = millis();

  if (portOne.available() == 0) { //see if serial port is open for output communication
    portOne.write(message, sizeof(message)); //send the info request to the BMS
  }
  portOne.listen(); Serial.println("1st Data Request:"); while (portOne.available() < 34);//Wait until 34 bytes have been received

  int n = portOne.readBytes(converter1.d, 34); // n is size of byte array received
  for (int i = 0; i < sizeof(converter1.d); i++) {
    Serial.print(converter1.d[i], HEX); //Prints out received message
    Serial.print(", ") ;
  }
  Serial.println(); Serial.print("Number of Bytes received: "); Serial.println(n);


  ByteSwap.b_array[0] = converter1.d[7]; ByteSwap.b_array[1] = converter1.d[6];
  Current_A = (double) - .01 * ByteSwap.swapped;
  Serial.print("Current: "); Serial.println(Current_A);
  //lcd.setCursor(9, 2); lcd.print(Current_A, 2);


  // ***Send 2nd request***
  byte message2[] = {0xdd, 0xa5, 0x04, 0x00, 0xff, 0xfc, 0x77};//Request info from BMS

  if (portOne.available() == 0) {
    portOne.write(message2, sizeof(message2));
  }
  portOne.listen(); Serial.println("2nd Data Request:"); while (portOne.available() < 37);
  int n2 = portOne.readBytes(converter2.d, 37); // n is size of byte array received
  for (int i = 0; i < sizeof(converter2.d); i++) {
    Serial.print(converter2.d[i], HEX);
    Serial.print(", ") ;
  }
  Serial.println(); Serial.print("Number of Bytes received: "); Serial.println(n2);

  double min_Voltage_V = 5; int index;
  double Total_Voltage_V = 0;
  for (int i = 1; i < 16; i++) {
    ByteSwap.b_array[0] = converter2.d[2 * i + 3]; ByteSwap.b_array[1] = converter2.d[2 * i + 2];
    Voltages_V[i] = (double)ByteSwap.swapped / 1000;
    Total_Voltage_V = Total_Voltage_V + Voltages_V[i]; //Add cell voltage to sum of voltages.
    if (Voltages_V[i] < min_Voltage_V) {
      index = i;
      min_Voltage_V = Voltages_V[i];
    }
    Serial.print("V"); Serial.print(i); Serial.print(": "); Serial.println(Voltages_V[i], 3);
  }

  lcd.setCursor(11, 2); lcd.print(Voltages_V[index], 2);
  Serial.print("Min Voltage: "); Serial.println(Voltages_V[index], 3);
  Serial.print("Index Num: "); Serial.println(index);

  double Power_W = Total_Voltage_V * Current_A;
  Serial.print("Power: "); Serial.println(Power_W, 2); Serial.println();
  lcd.setCursor(11, 3); lcd.print(Power_W, 1);

}

void setDisplay() {
  lcd.begin(20, 4);
  lcd.print("            ");
  lcd.setCursor(0, 1);  lcd.print("Speed: ");
  lcd.setCursor(0, 0);  lcd.print("Dist :");
  lcd.setCursor(16, 0); lcd.print("mi");
  lcd.setCursor(16, 1); lcd.print("mph");
  lcd.setCursor(0, 3); lcd.print("Power: ");
  lcd.setCursor(0, 2); lcd.print("MinVolt: ");
  lcd.setCursor(16, 3); lcd.print("W");
  lcd.setCursor(16, 2); lcd.print("V");
}

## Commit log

2019-02-09 Added Folders to organize files
    [Arduino_Shield_1_19_19_REV0.brd, Arduino_Shield_1_19_19_REV0.sch]
2019-02-10 Added BETA version of Arduino software
2019-04-02 Added updated EAGLE Files
    Includes DC/DC converter, capacitor, and better labeling silkscreens
    [Arduino_Shield_3_4_19_REV2.brd, Arduino_Shield_3_4_19_REV2.sch]
2019-06-06 Updated High Level Design
    Refurbishing schematic dseign for clarity
    [Arduino_Shield_1_19_19_REV0.brd, Arduino_Shield_1_19_19_REV0.sch, Arduino_Shield_3_4_19_REV2.brd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]
2019-06-21 Completed REV3 of board
    REV adds a larger DC/DC converter and connector for a 12V headlight
    [Arduino_Shield_6_5_19_REV3.brd, Arduino_Shield_6_5_19_REV3.sch]
2019-07-08 Completed REV4
    [Arduino_Shield_6_5_19_REV4.brd, Arduino_Shield_6_5_19_REV4.sch, BOM.xlsx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]
2019-07-11 REV4 is Complete, PCB and BOM sent out
    Evaluation of REV4 will be completed by the end of July
    [Arduino_Shield_6_5_19_REV4.brd, Arduino_Shield_6_5_19_REV4.sch, Arduino_Shield_REV4_BOM.xlsx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]
2019-07-25 Corrected polarity of DCDC converter of REV4 board
    [Arduino_Shield_6_5_19_REV4.brd, Spacer_REV3_07_09_19.SLDPRT, Spacer_REV3_07_09_19.STL]
2019-07-26 Completed REV3
    REV3 is identical to REV4 but uses an off the shelf arduino nano.
    [Arduino_Shield_6_5_19_REV3.brd, Arduino_Shield_6_5_19_REV3.sch]
2019-07-28 Updated REV4 to include fuse & input polarity protection
    [Arduino_Shield_REV4_BOM.xlsx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]

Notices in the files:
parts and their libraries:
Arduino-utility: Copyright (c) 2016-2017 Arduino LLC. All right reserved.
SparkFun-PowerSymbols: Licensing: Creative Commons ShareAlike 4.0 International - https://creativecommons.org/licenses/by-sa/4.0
